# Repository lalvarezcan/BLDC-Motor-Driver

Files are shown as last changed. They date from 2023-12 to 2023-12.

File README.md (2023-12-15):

# BLDC Motor Driver for MIT Mini Cheetah Actuator

This driver is designed specifically for use with the Quasi-Direct Driver (QDD) Actuators, inspired by the work of Ben Katz. The driver is intended to efficiently deliver power and control a BLDC Motor, enabling precise and agile movements.

## Overview

The BLDC Motor Driver is a crucial component in the Quasi-Driect Drive (QDD) Actuator system, responsible for managing the power and control signals sent to the brushless DC motors. It ensures smooth operation, speed control, and torque management for the actuators, contributing to the overall performance of the robotic system.

## Features

- **Brushless DC Motor Control:** Offers precise control over the motors used in the Mini Cheetah Actuator.
- **PWM (Pulse Width Modulation) Control:** Enables accurate speed control and torque management.
- **Communication Interface:** Interfaces with the main control system via a specified communication protocol (e.g., SPI, CAN, UART).
- **Overcurrent and Overvoltage Protection:** Safeguards the system and motors against potential damage due to excessive current or voltage.

## Hardware Requirements

- **BLDC Motors:** Compatible with the motors specified for the MIT Mini Cheetah Actuator.
- **Microcontroller or Control Board:** Interfaces with the driver to send control signals.
- **Power Supply:** Provides the necessary voltage and current for the motors.

## Installation and Setup

1. **Hardware Connections:** Connect the driver to the specified ports on the control board and motors as per the provided documentation or pinout details.
2. **Power Supply:** Ensure the power supply meets the voltage and current requirements of the motors.
3. **Control Interface:** Establish communication between the driver and the main control system using the designated communication protocol.
4. **Software Integration:** Implement the necessary control algorithms or software libraries to interact with the driver and control the motors effectively.

## Usage

- **Initialization:** Initialize the driver and configure the necessary parameters (e.g., PWM frequency, motor direction, etc.).
- **Control Commands:** Send control commands via the designated communication interface to adjust motor speed, direction, and torque as required.
- **Monitoring:** Implement monitoring mechanisms to keep track of motor performance, temperature, and any potential faults.

## Contributors

- Luis Avarez (CINVESTAV Guadalajara)

## License

This project is licensed under [MIT License](LICENSE.md).

## Acknowledgments

- Ben Katz (Original MIT Mini Cheetah Actuator Design)

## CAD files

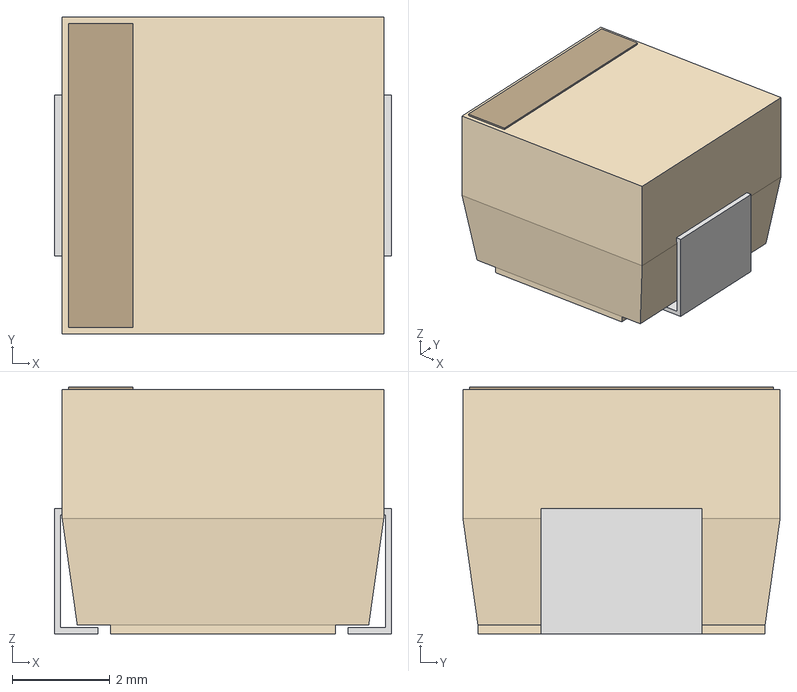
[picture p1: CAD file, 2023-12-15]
IND_ELL6UH-M.step
6.91 x 6.50 x 5.05 mm

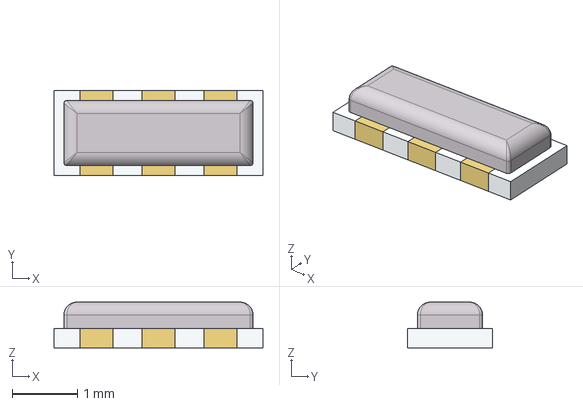
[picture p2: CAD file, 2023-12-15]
ceramic-resonator-smd-3mm2x1mm3-muratea-cstce.stp
3.20 x 1.30 x 0.7 mm

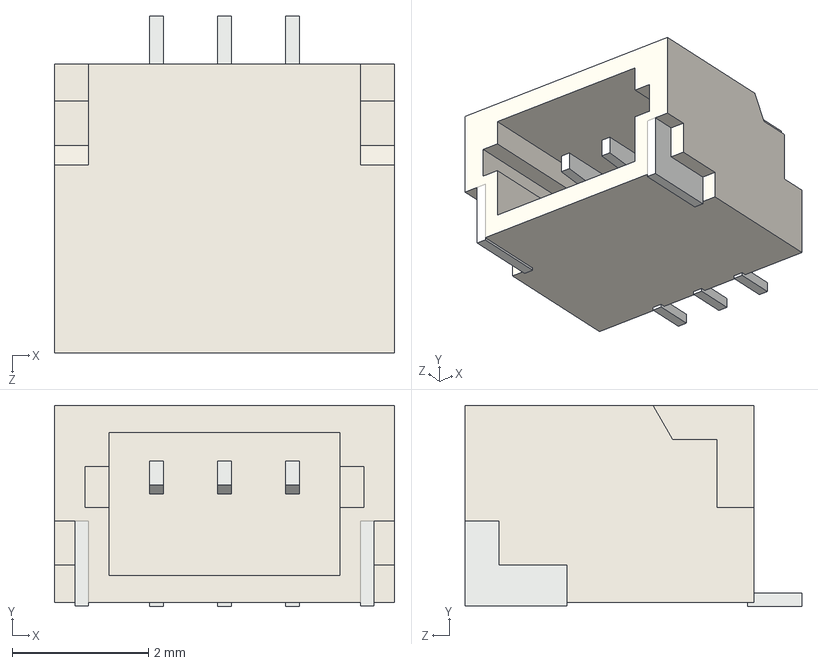
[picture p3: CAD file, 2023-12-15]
SM03B-SRSS-TB.STEP
5.00 x 2.96 x 4.95 mm

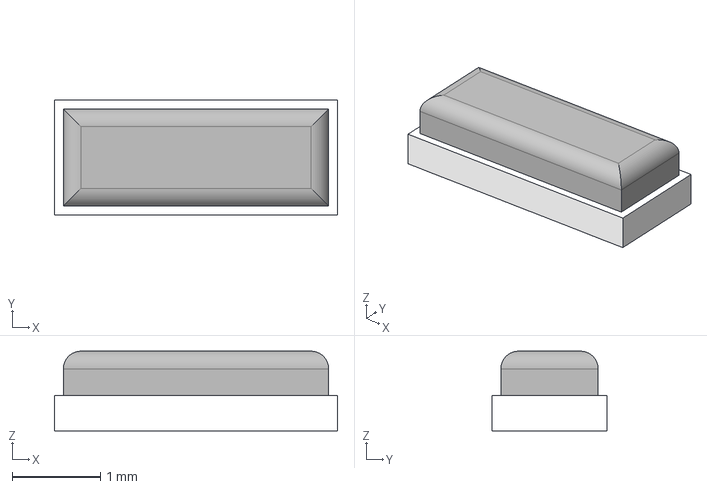
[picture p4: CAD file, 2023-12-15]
MURATA - CSTNE.step
3.20 x 1.30 x 0.901 mm

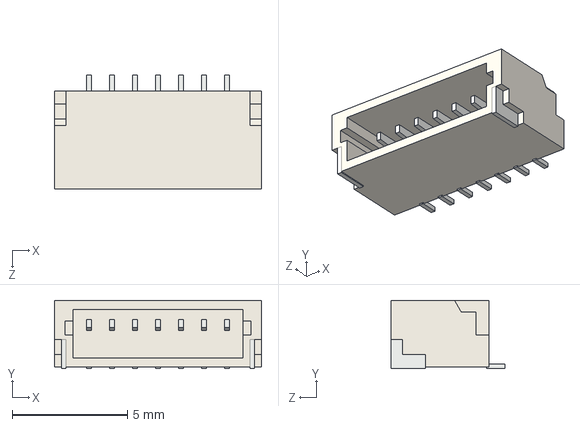
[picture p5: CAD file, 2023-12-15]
SM07B-SRSS-TB.STEP
9.00 x 2.96 x 4.95 mm

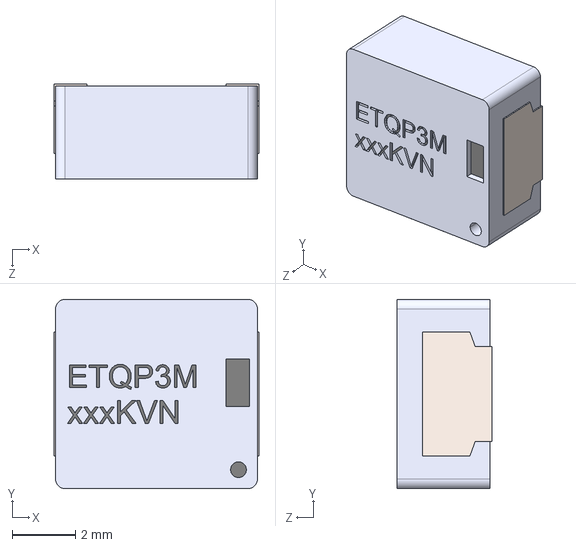
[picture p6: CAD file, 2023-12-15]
InductorPanasonic.STEP
6.50 x 6.00 x 3.00 mm
User Library-L Panasonic ETQP3MxxxKVN_Body
User Library-L Panasonic ETQP3MxxxKVN_Pin x 2

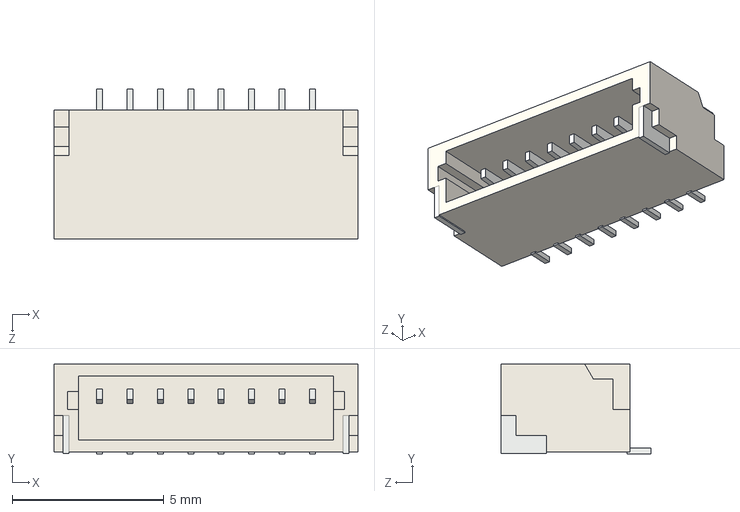
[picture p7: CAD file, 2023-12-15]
SM08B-SRSS-TB.step
10.0 x 2.96 x 4.95 mm

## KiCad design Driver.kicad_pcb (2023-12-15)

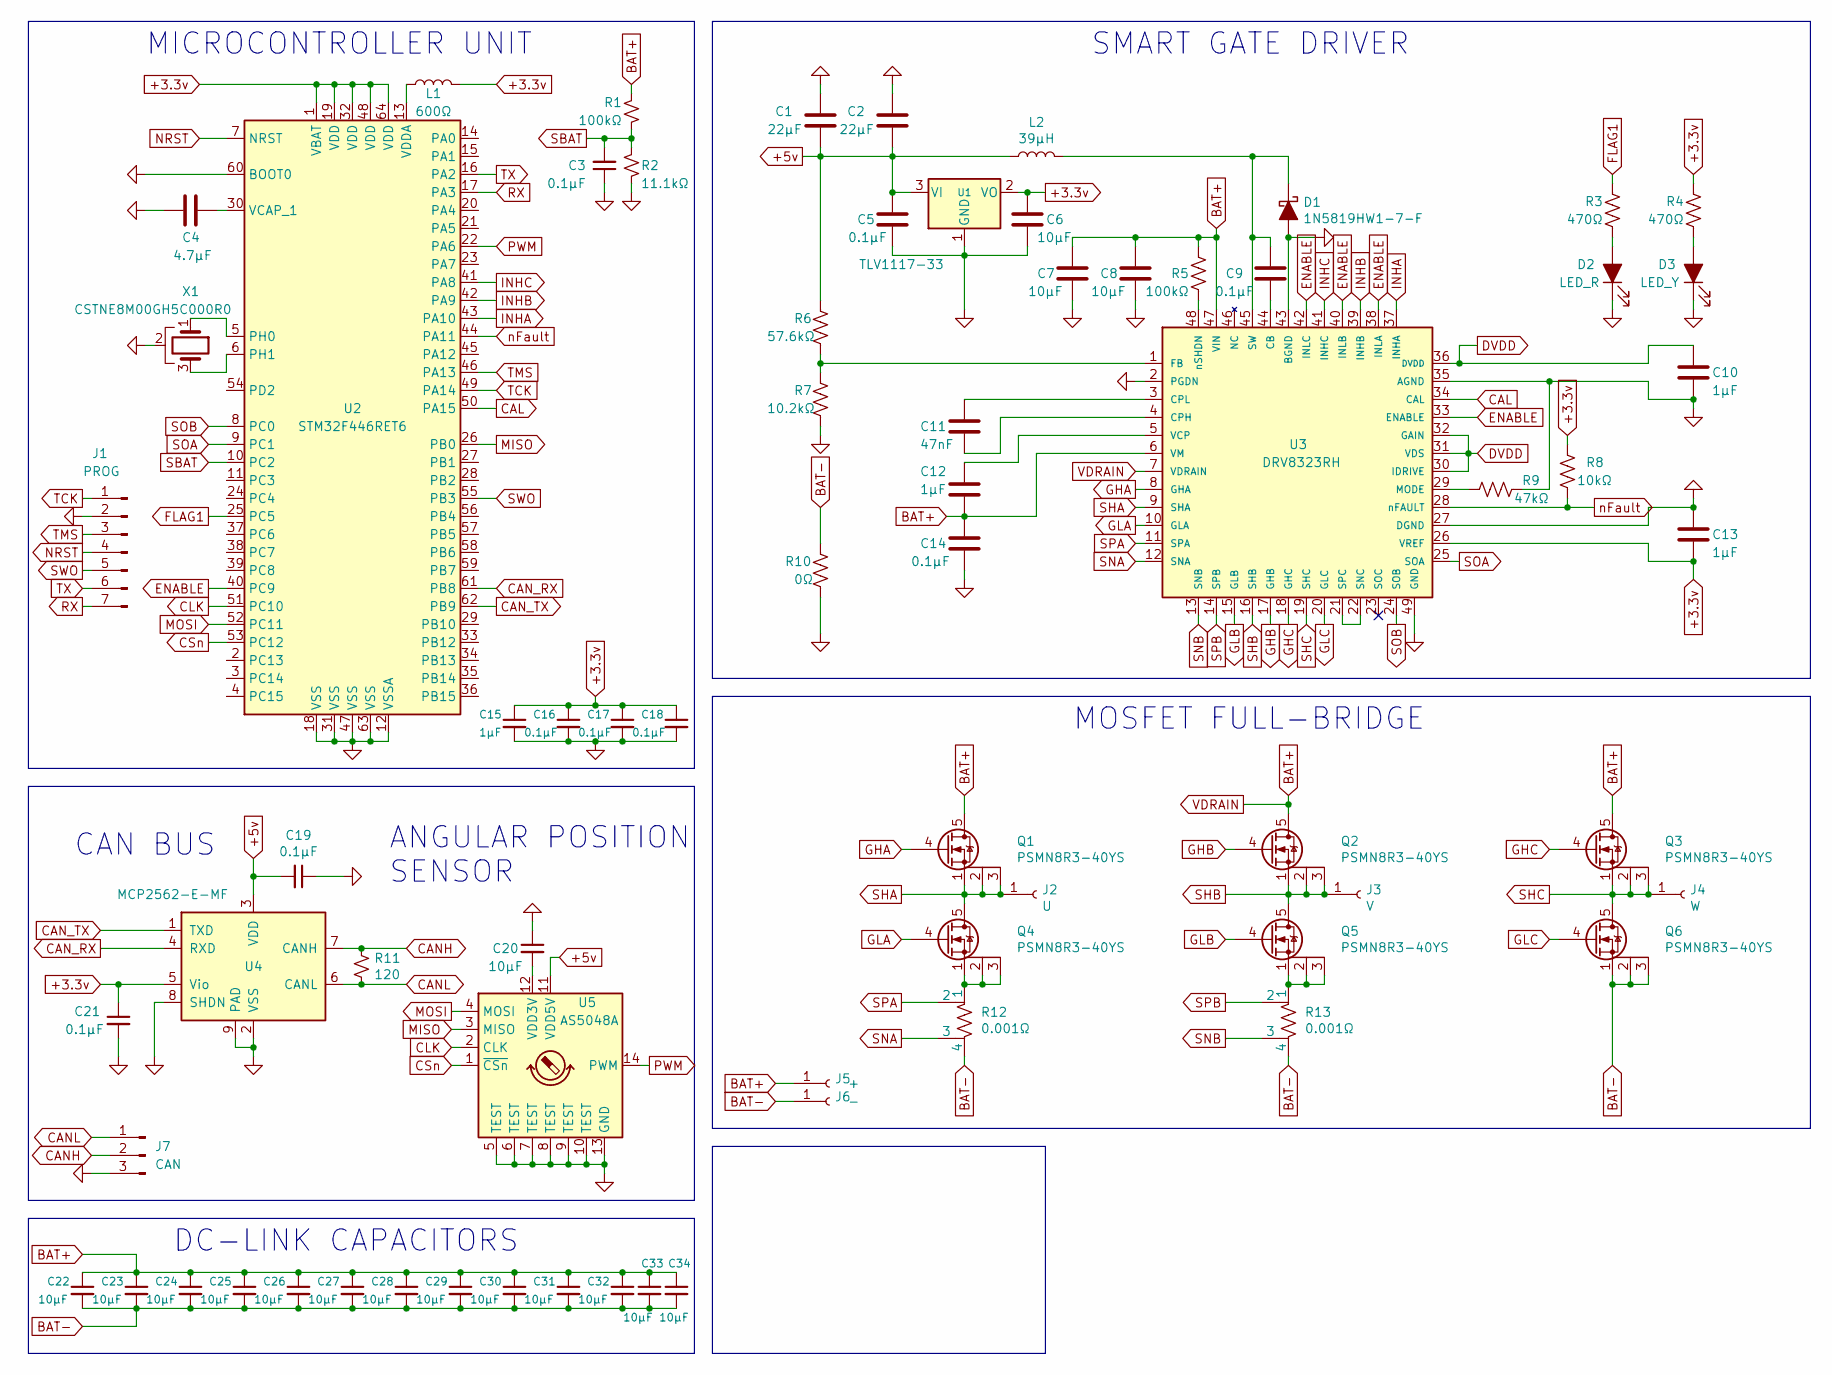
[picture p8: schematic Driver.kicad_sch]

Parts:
C1, C2: 22µF; C_0805_2012Metric
C3, C5, C9, C14, C16, C17, C18, C19, C21: 0.1µF; C_0805_2012Metric
C4: 4.7µF; C_0805_2012Metric
C6, C7, C8, C20: 10µF; C_0805_2012Metric
C10, C12, C13, C15: 1µF; C_0805_2012Metric
C11: 47nF; C_0805_2012Metric
C22, C23, C24, C25, C26, C27, C28, C29, C30, C31, C32, C33, C34: 10µF; C_1206_3216Metric
D1: 1N5819HW1-7-F; D_SOD-123F
D2: LED_R; LED_0603_1608Metric_Pad1.05x0.95mm_HandSolder
D3: LED_Y; LED_0603_1608Metric_Pad1.05x0.95mm_HandSolder
J1: PROG; JST_SH_SM07B-SRSS-TB_1x07-1MP_P1.00mm_Horizontal
J2: U; drillhole
J3: V; drillhole
J4: W; drillhole
J5: +; drillhole
J6: -; drillhole
J7: CAN; JST_SH_SM03B-SRSS-TB_1x03-1MP_P1.00mm_Horizontal
L1: 600Ω; L_0805_2012Metric
L2: 39µH; ELL6UH390M
Q1, Q2, Q3, Q4, Q5, Q6: PSMN8R3-40YS; LFPAK56
R1, R5: 100kΩ; R_0805_2012Metric
R2: 11.1kΩ; R_0805_2012Metric
R3, R4: 470Ω; R_0805_2012Metric
R6: 57.6kΩ; R_0805_2012Metric
R7: 10.2kΩ; R_0805_2012Metric
R8: 10kΩ; R_0805_2012Metric
R9: 47kΩ; R_0805_2012Metric
R10: 0Ω; R_1206_3216Metric
R11: 120; R_0805_2012Metric
R12, R13: 0.001Ω; R_Shunt_2512_6332Metric
U1: TLV1117-33; Texas_S-PVSON-N8
U2: STM32F446RET6; LQFP-64_10x10mm_P0.5mm
U3: DRV8323RH; Texas_S-PVQFN-N48_EP5.15x5.15mm_ThermalVias
U4: MCP2562-E-MF; DFN-8-1EP_3x3mm_P0.65mm_EP1.55x2.4mm
U5: AS5048A; TSSOP-14_4.4x5mm_P0.65mm
X1: CSTNE8M00GH5C000R0; Resonator_SMD_muRata_CSTxExxV-3Pin_3.0x1.1mm

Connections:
+3.3v: C6.2, C13.1, C15.1, C16.1, C17.1, C18.1, C21.1, L1.2, R4.2, R8.1, U1.2 (VO), U2.1 (VBAT), U2.19 (VDD), U2.32 (VDD), U2.48 (VDD), U2.64 (VDD), U3.26 (VREF), U4.5 (Vio)
+5v: C1.2, C2.2, C5.2, C19.2, L2.1, R6.1, U1.3 (VI), U4.3 (VDD), U5.11 (VDD5V)
BAT+: C7.2, C8.2, C12.1, C14.2, C22.1, C23.1, C24.1, C25.1, C26.1, C27.1, C28.1, C29.1, C30.1, C31.1, C32.1, C33.1, C34.1, J5.1, Q1.5 (D), Q2.5 (D), Q3.5 (D), R1.1, R5.2, U3.6 (VM), U3.7 (VDRAIN), U3.47 (VIN)
BAT-: C22.2, C23.2, C24.2, C25.2, C26.2, C27.2, C28.2, C29.2, C30.2, C31.2, C32.2, C33.2, C34.2, J6.1, Q6.1 (S), Q6.2 (S), Q6.3 (S), R10.1, R12.4, R13.4
CAL: U2.50 (PA15), U3.34 (CAL)
CANH: J7.2, R11.1, U4.7 (CANH)
CANL: J7.1, R11.2, U4.6 (CANL)
CAN_RX: U2.61 (PB8), U4.4 (RXD)
CAN_TX: U2.62 (PB9), U4.1 (TXD)
CLK: U2.51 (PC10), U5.2 (CLK)
CSn: U2.53 (PC12), U5.1 (~CSn)
DVDD: C10.2, U3.30 (IDRIVE), U3.31 (VDS), U3.32 (GAIN), U3.36 (DVDD)
ENABLE: U2.40 (PC9), U3.33 (ENABLE), U3.38 (INLA), U3.40 (INLB), U3.42 (INLC)
FLAG1: R3.2, U2.25 (PC5)
GHA: Q1.4 (G), U3.8 (GHA)
GHB: Q2.4 (G), U3.17 (GHB)
GHC: Q3.4 (G), U3.18 (GHC)
GLA: Q4.4 (G), U3.10 (GLA)
GLB: Q5.4 (G), U3.15 (GLB)
GLC: Q6.4 (G), U3.20 (GLC)
GND: C1.1, C2.1, C3.1, C4.1, C5.1, C6.1, C7.1, C8.1, C10.1, C13.2, C14.1, C15.2, C16.2, C17.2, C18.2, C19.1, C20.1, C21.2, D1.2 (A), D2.1 (K), D3.1 (K), J1.2, J7.3, R2.1, R7.2, R9.2, R10.2, U1.1 (GND), U2.12 (VSSA), U2.18 (VSS), U2.31 (VSS), U2.47 (VSS), U2.60 (BOOT0), U2.63 (VSS), U3.2 (PGDN), U3.27 (DGND), U3.35 (AGND), U3.43 (BGND), U3.49 (GND), U4.2 (VSS), U4.8 (SHDN), U4.9 (PAD), U5.5 (TEST), U5.6 (TEST), U5.7 (TEST), U5.8 (TEST), U5.9 (TEST), U5.10 (TEST), U5.13 (GND), X1.2
INHA: U2.43 (PA10), U3.37 (INHA)
INHB: U2.42 (PA9), U3.39 (INHB)
INHC: U2.41 (PA8), U3.41 (INHC)
MISO: U2.26 (PB0), U5.3 (MISO)
MOSI: U2.52 (PC11), U5.4 (MOSI)
NRST: J1.4, U2.7 (NRST)
unnamed: C4.2, U2.30 (VCAP_1)
unnamed: C9.1, U3.44 (CB)
unnamed: C9.2, D1.1 (K), L2.2, U3.45 (SW)
unnamed: C11.1, U3.4 (CPH)
unnamed: C11.2, U3.3 (CPL)
unnamed: C12.2, U3.5 (VCP)
unnamed: C20.2, U5.12 (VDD3V)
unnamed: D2.2 (A), R3.1
unnamed: D3.2 (A), R4.1
unnamed: L1.1, U2.13 (VDDA)
unnamed: Q4.1 (S), Q4.2 (S), Q4.3 (S), R12.1
unnamed: Q5.1 (S), Q5.2 (S), Q5.3 (S), R13.1
unnamed: R5.1, U3.48 (nSHDN)
unnamed: R6.2, R7.1, U3.1 (FB)
unnamed: R9.1, U3.29 (MODE)
unnamed: U2.5 (PH0), X1.1
unnamed: U2.6 (PH1), X1.3
unnamed: U3.21 (SPC), U3.22 (SNC)
PWM: U2.22 (PA6), U5.14 (PWM)
RX: J1.7, U2.17 (PA3)
SBAT: C3.2, R1.2, R2.2, U2.10 (PC2)
SHA: J2.1, Q1.1 (S), Q1.2 (S), Q1.3 (S), Q4.5 (D), U3.9 (SHA)
SHB: J3.1, Q2.1 (S), Q2.2 (S), Q2.3 (S), Q5.5 (D), U3.16 (SHB)
SHC: J4.1, Q3.1 (S), Q3.2 (S), Q3.3 (S), Q6.5 (D), U3.19 (SHC)
SNA: R12.3, U3.12 (SNA)
SNB: R13.3, U3.13 (SNB)
SOA: U2.9 (PC1), U3.25 (SOA)
SOB: U2.8 (PC0), U3.24 (SOB)
SPA: R12.2, U3.11 (SPA)
SPB: R13.2, U3.14 (SPB)
SWO: J1.5, U2.55 (PB3)
TCK: J1.1, U2.49 (PA14)
TMS: J1.3, U2.46 (PA13)
TX: J1.6, U2.16 (PA2)
nFault: R8.2, U2.44 (PA11), U3.28 (nFAULT)

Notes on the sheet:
MOSFET FULL-BRIDGE
CAN BUS
ANGULAR POSITION SENSOR
SMART GATE DRIVER
DC-LINK CAPACITORS
MICROCONTROLLER UNIT

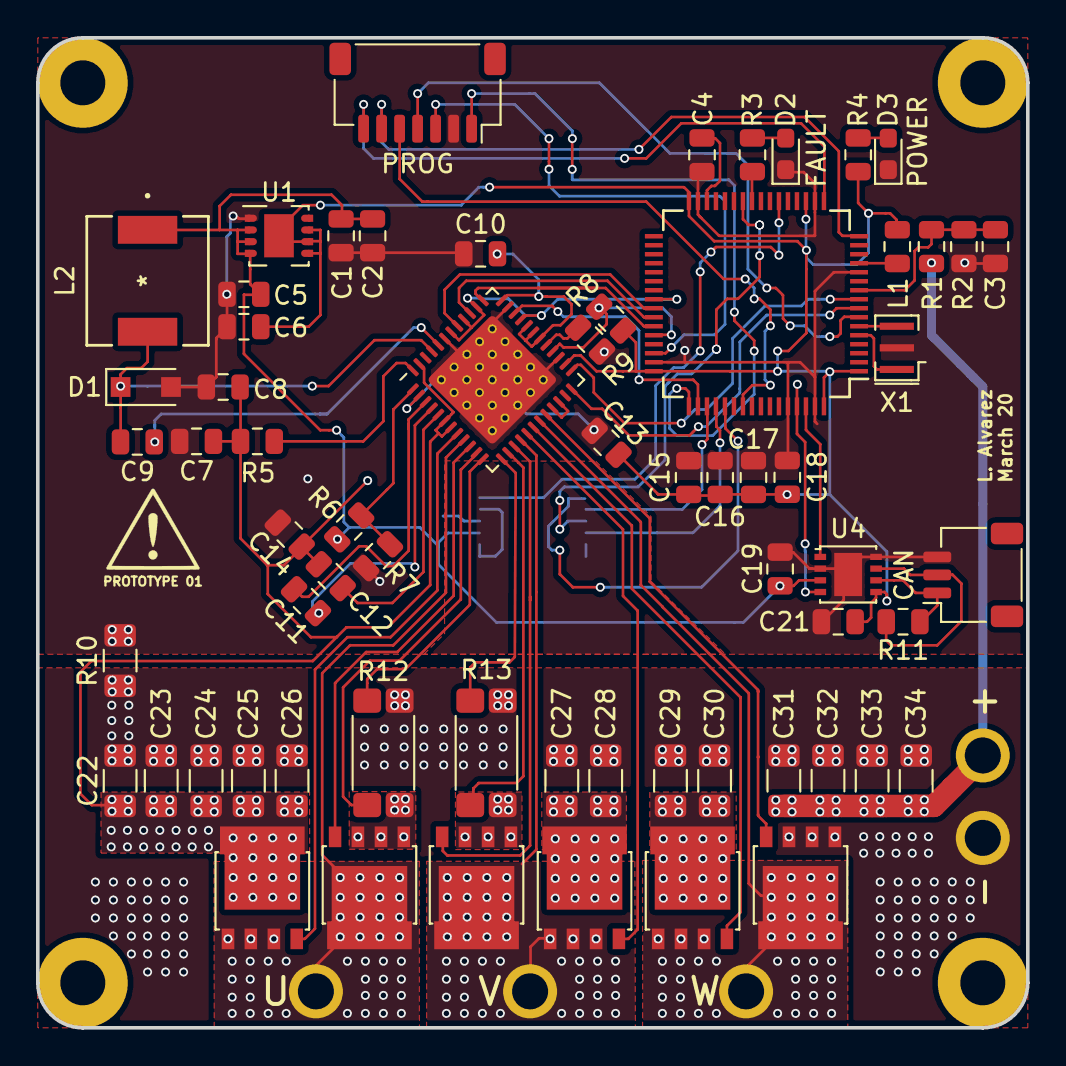
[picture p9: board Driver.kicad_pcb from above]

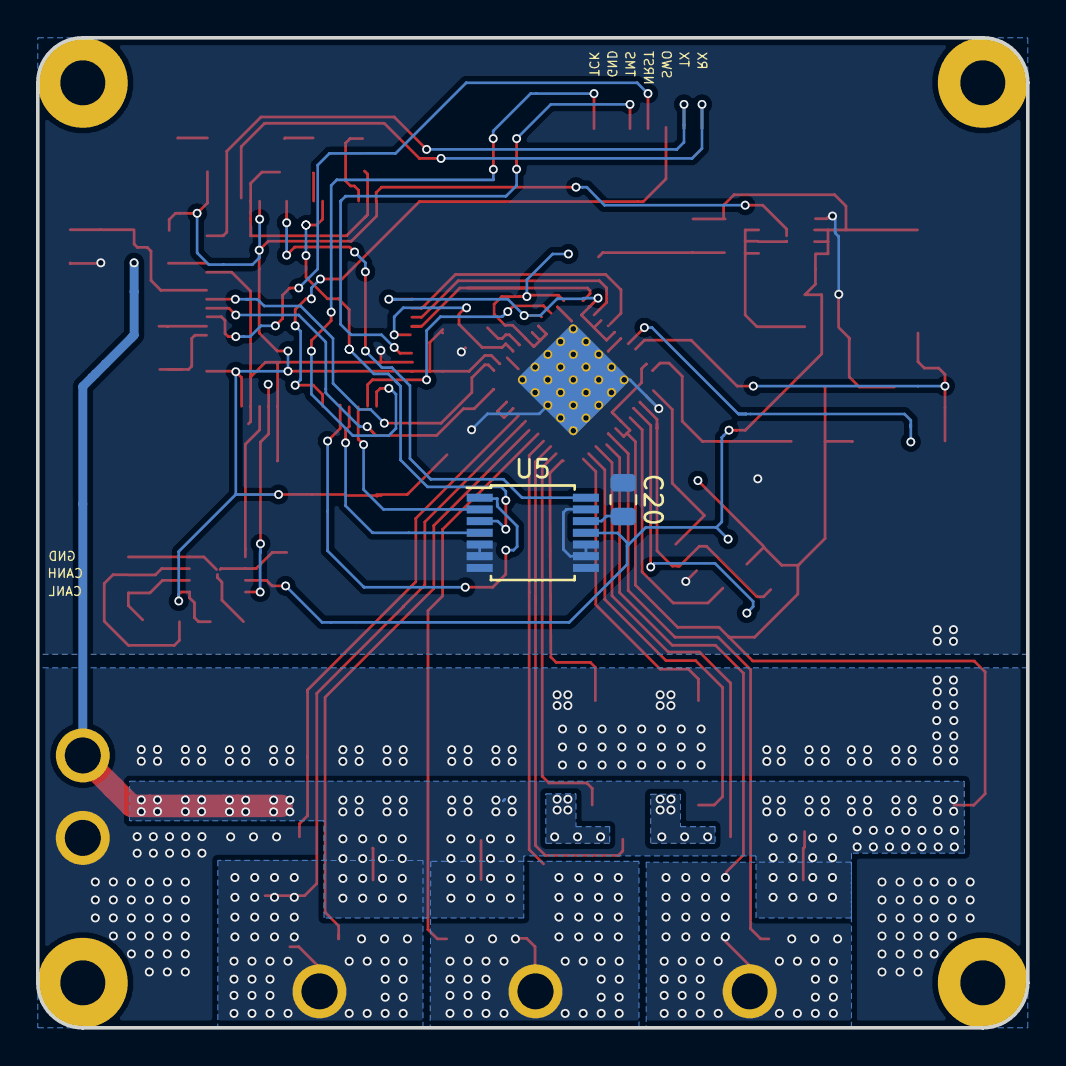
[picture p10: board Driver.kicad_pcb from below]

Board: 2 copper layers, 55.0 x 55.0 mm, 71 parts (2 on the bottom side), 62 nets.
